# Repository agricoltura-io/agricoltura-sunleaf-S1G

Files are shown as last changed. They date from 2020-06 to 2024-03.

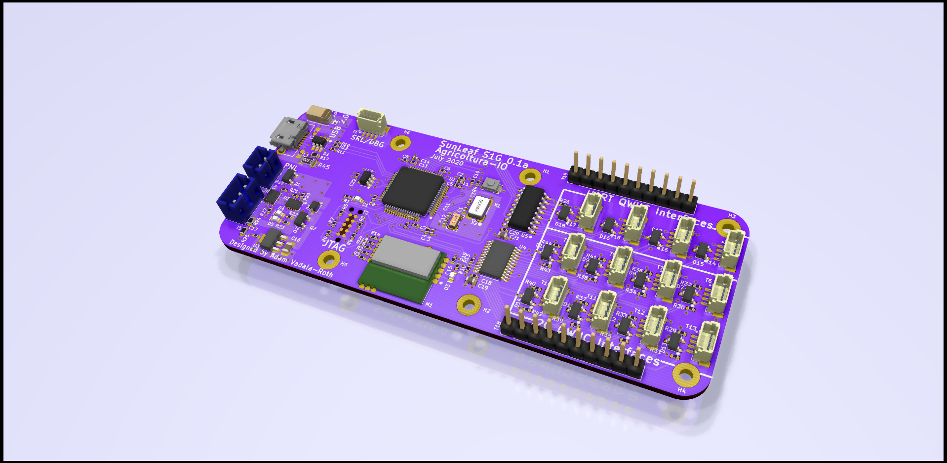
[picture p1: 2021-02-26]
PCB/agricoltura-SunLeaf-S1G/agricoltura-SunLeaf-S1G_angledRaytraced.png

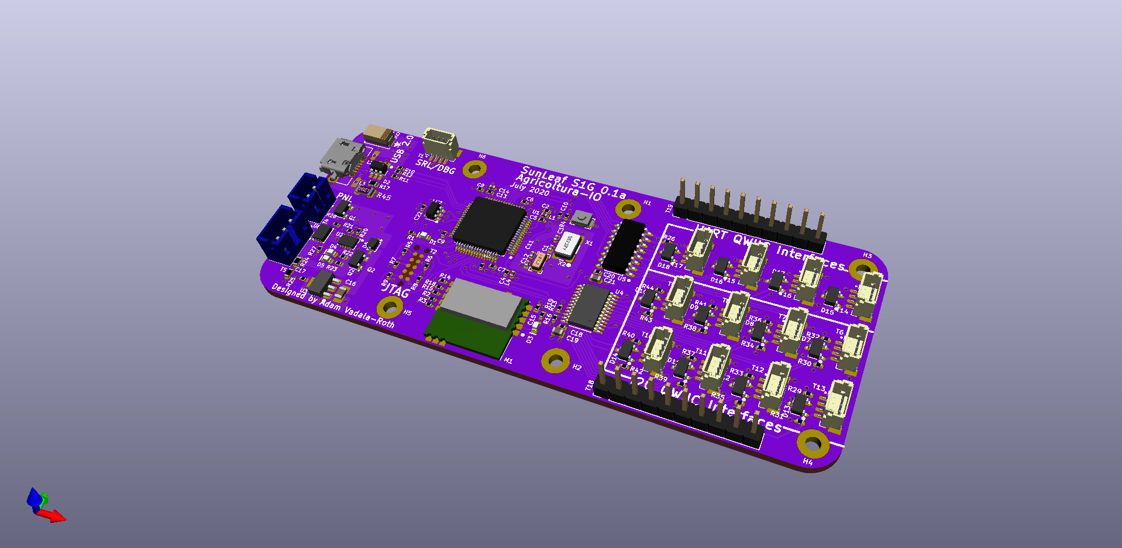
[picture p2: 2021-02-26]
PCB/agricoltura-SunLeaf-S1G/agricoltura-SunLeaf-S1G_angled.png

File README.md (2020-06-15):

# agricoltura-sunleaf-S1G
A new generation of the SunLeaf platform based on STM32 S1G radio module

Quick Specs:
- ST Microelectronics SPSGRF-915 STM32 ARM Cortex M0 915MHZ RF Module
- BQ240210 Lithium Ion Solar/USB charge controller and battery management 
- 500mA Lithium Polymer battery with thermistor 
- I2C ports
- UART ports
- Analog ports

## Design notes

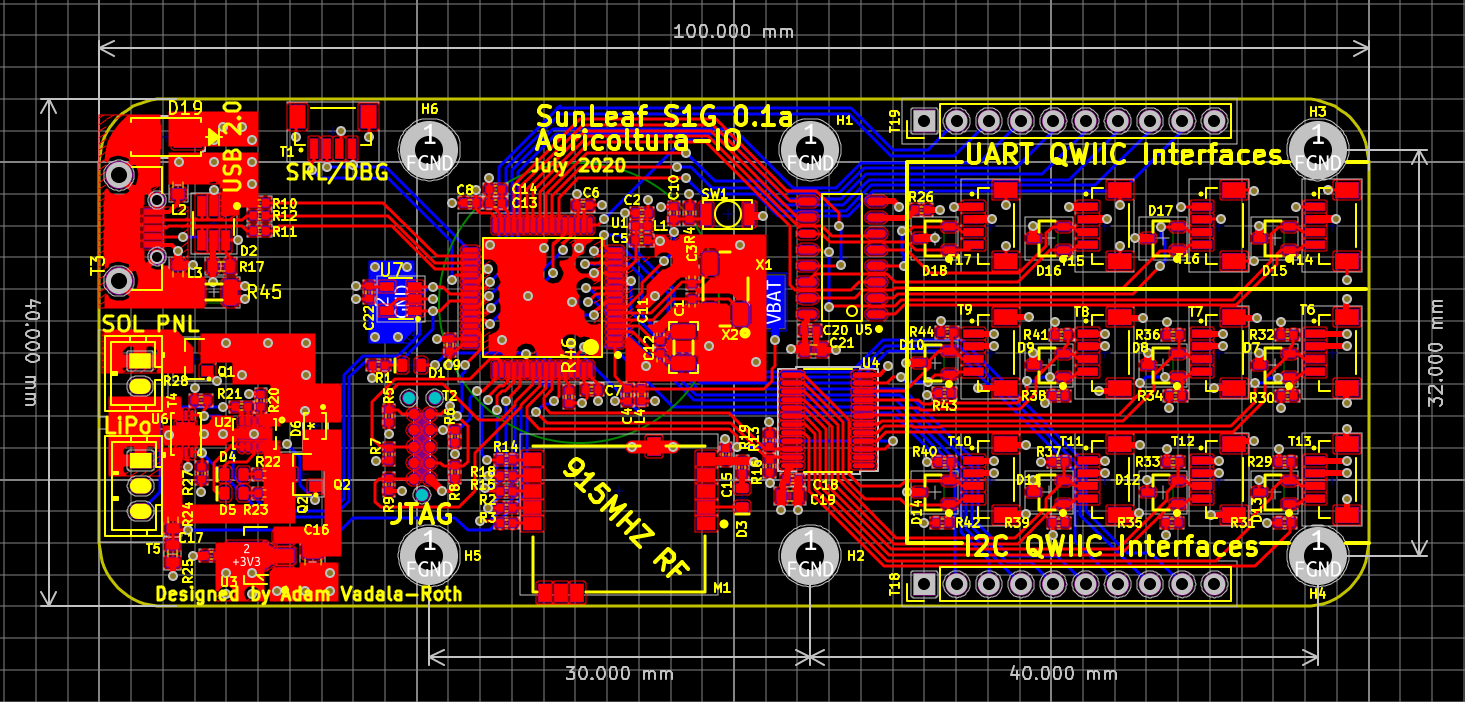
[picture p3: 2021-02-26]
PCB/agricoltura-SunLeaf-S1G/SunLeafS1G2D.png

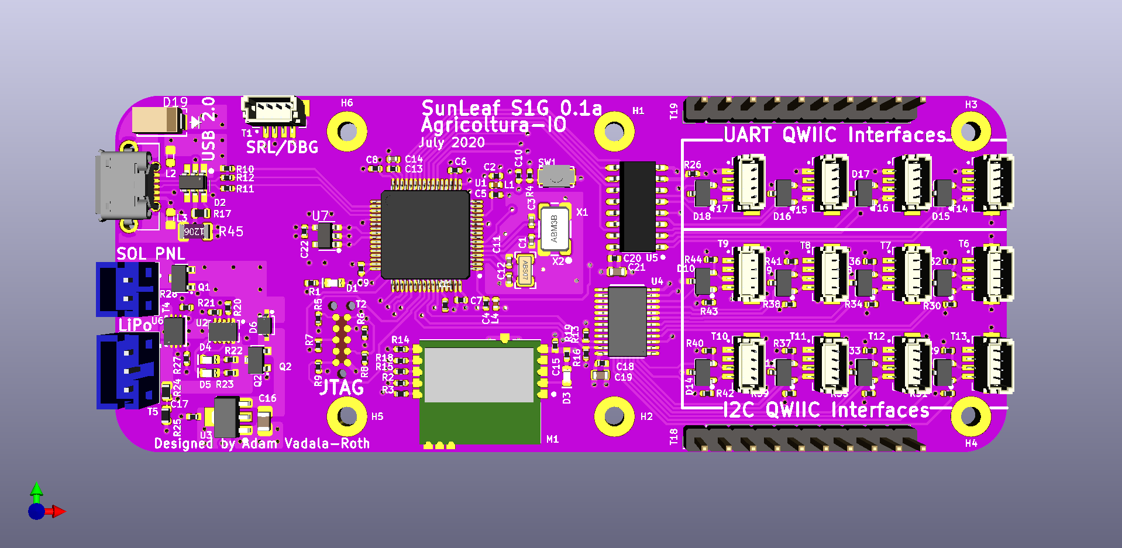
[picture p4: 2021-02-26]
PCB/agricoltura-SunLeaf-S1G/agricoltura-SunLeaf-S1G.png

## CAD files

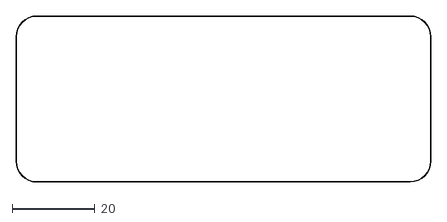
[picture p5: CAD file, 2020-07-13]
PCB/agricoltura-SunLeaf-S1G/SunLeaf_Board_Shape.dxf
100.0 x 40.0

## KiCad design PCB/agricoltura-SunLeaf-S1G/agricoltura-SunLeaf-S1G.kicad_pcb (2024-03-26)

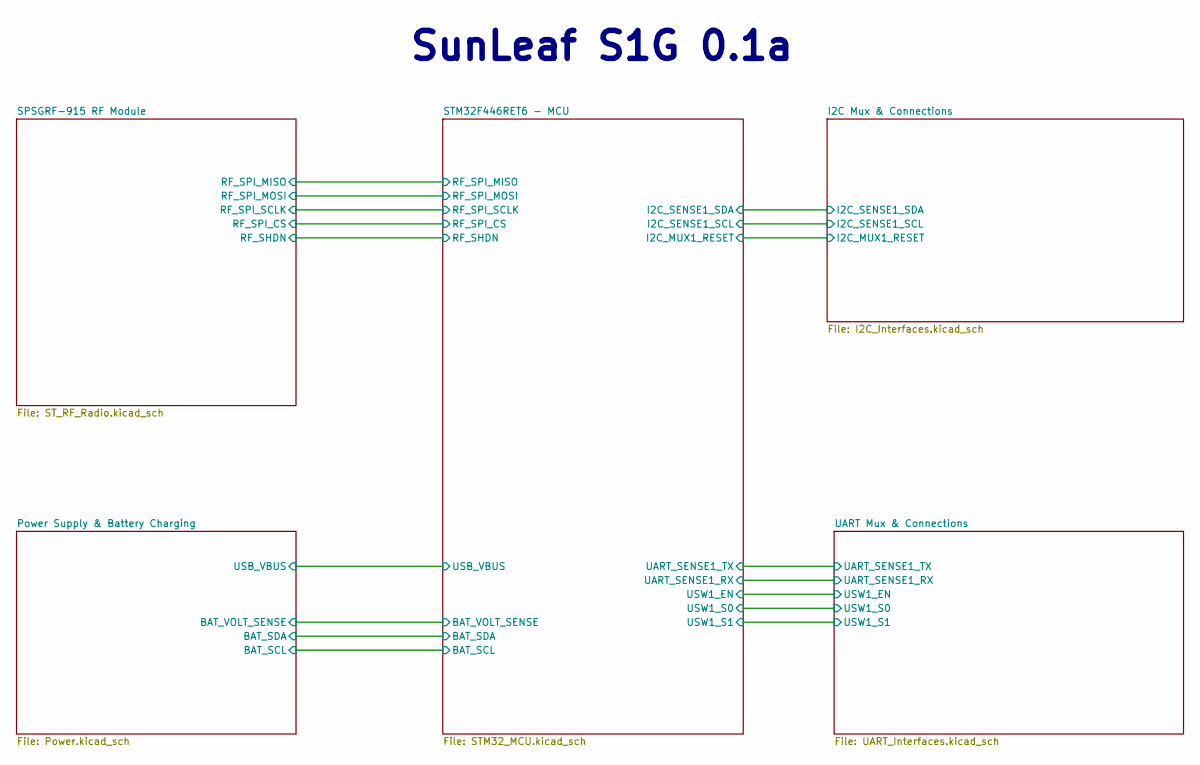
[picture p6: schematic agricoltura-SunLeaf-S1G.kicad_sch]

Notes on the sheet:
SunLeaf S1G 0.1a

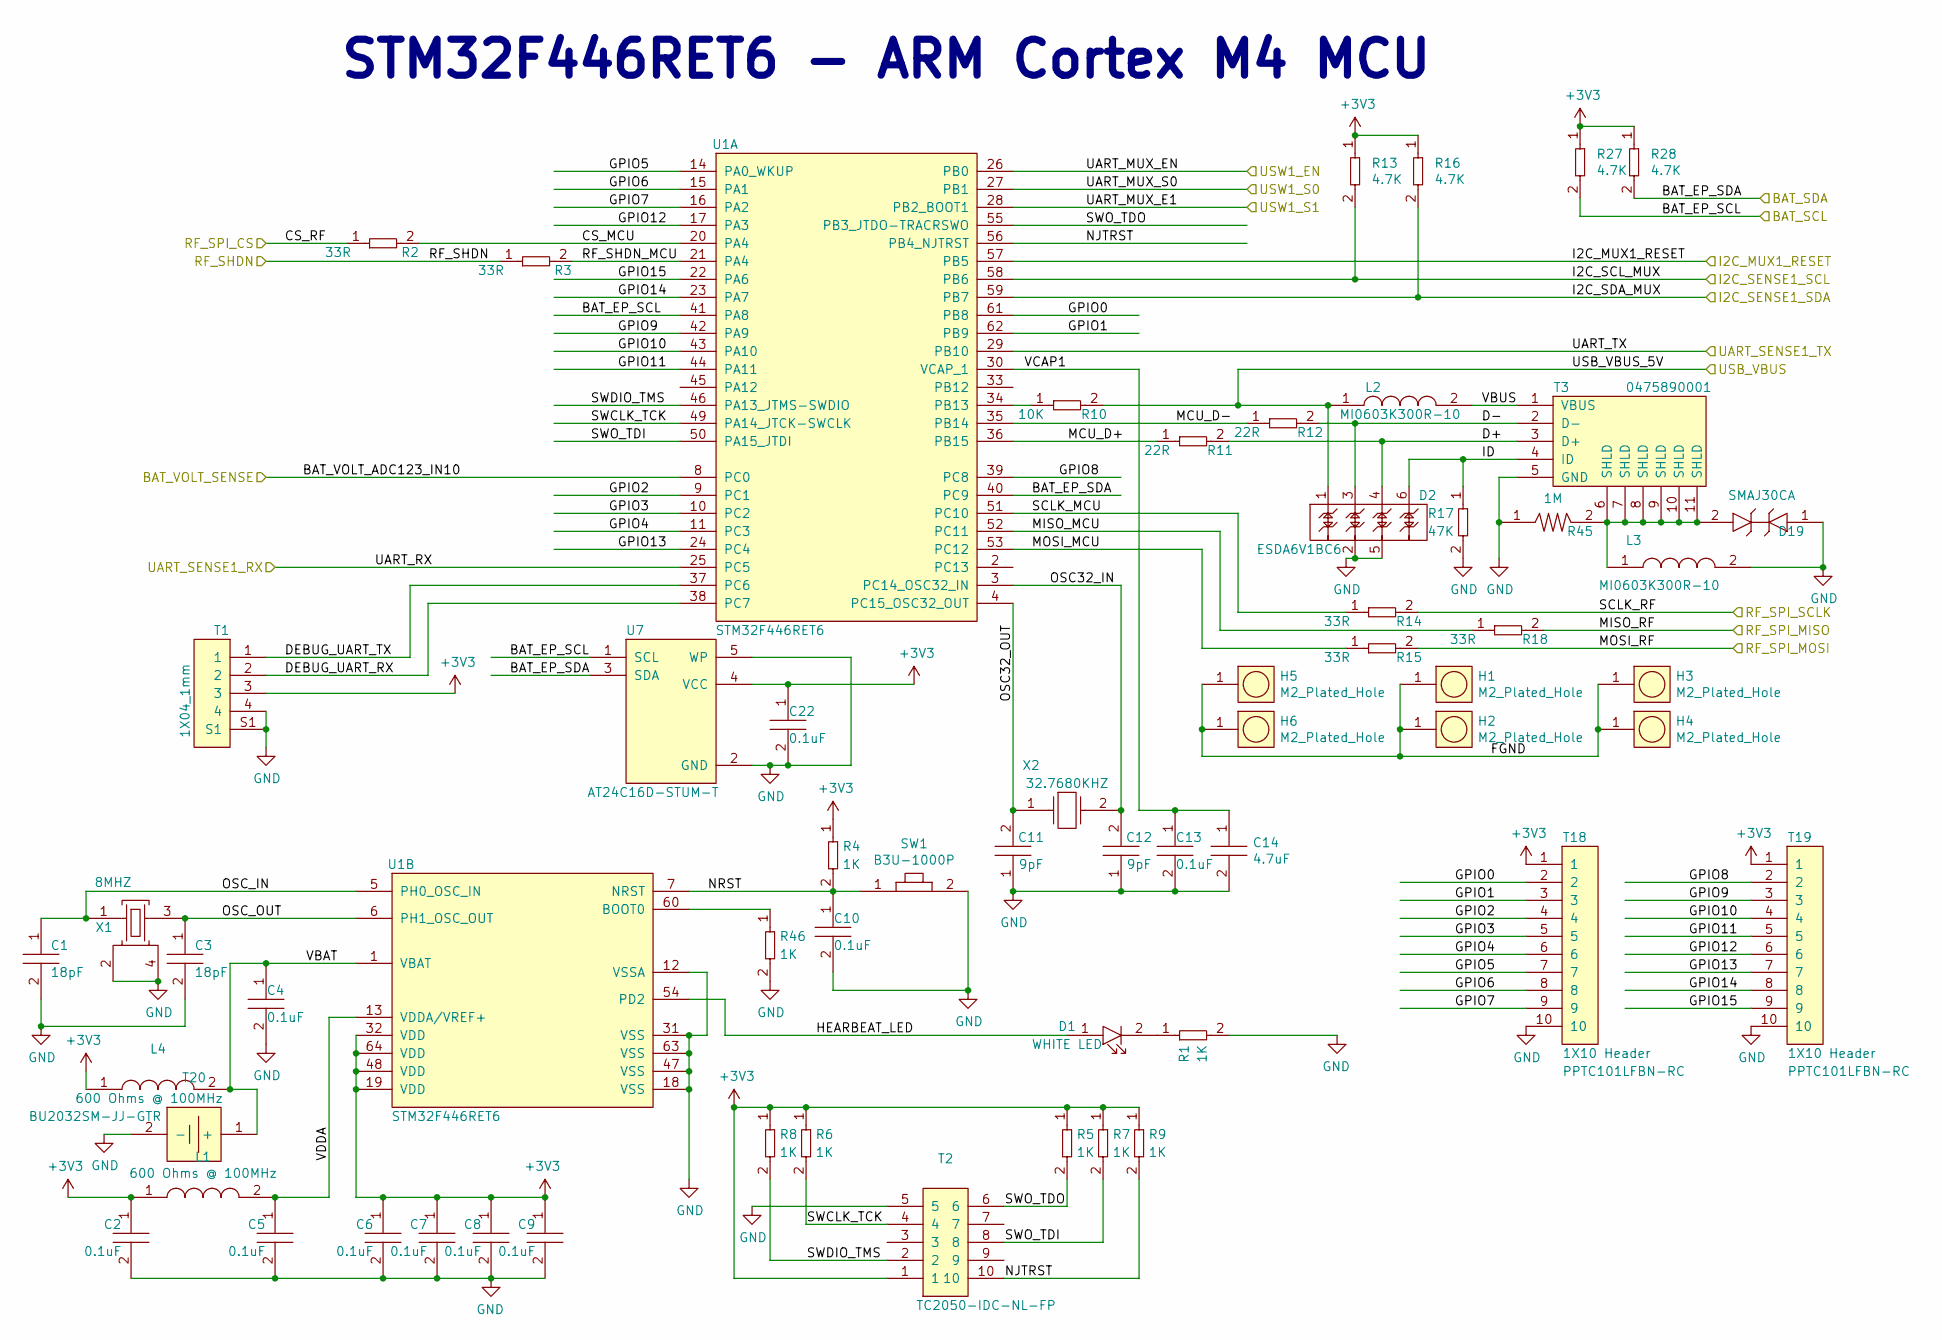
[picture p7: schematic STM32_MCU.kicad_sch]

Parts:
C1, C3: GCM1555C1H180GA16D; C0402; Tolerance 2%; Voltage 50V; MFR# GCM1555C1H180GA16D
C2, C4, C5, C6, C7, C8, C9, C10, C13, C22: C0402C104K9PACTU; R0402; Tolerance 10%; Voltage 6.3V; MFR# C0402C104K9PACTU
C11, C12: CL05C090CB5NNNC; C0402; Tolerance ±0.25pF; Voltage 50V; MFR# CL05C090CB5NNNC
C14: GRM155R60J475ME47D; C0402; Tolerance 20%; Voltage 6.3V; MFR# GRM155R60J475ME47D
D1: LW_Q38G_Q1OO_3K6L_1; LED0603; Tolerance *; Voltage 2.85V; MFR# LW Q38G-Q1OO-3K6L-1
D2: ESDA6V1BC6; SOT-23-6_Handsoldering; Tolerance *; Voltage 5V/6.1VBreakdown; MFR# ESDA6V1BC6
D19: SMAJ30CA; Tolerance *; Voltage 30V Clamp; MFR# SMAJ30CA
H1, H2, H3, H4, H5, H6: M2_Plated_Hole; M2_HOLE; Tolerance *; Voltage *; MFR# *
L1, L4: BLM15HG601SN1D; Tolerance *; Voltage *; MFR# BLM15HG601SN1D
L2, L3: MI0603K300R-10; Tolerance *; Voltage *; MFR# MI0603K300R-10
R1, R4, R5, R6, R7, R8, R9, R46: RC0402FR-071KL; R0402; Tolerance 1%; Voltage *; MFR# RC0402FR-071KL
R2, R3, R14, R15, R18: RC0402FR-0733RL; R0402; Tolerance 1%; Voltage *; MFR# RC0402FR-0733RL
R10: RC0402FR-0710KL; R0402; Tolerance 1%; Voltage *; MFR# RC0402FR-0710KL
R11, R12: RC0402FR-0722RL; R0402; Tolerance 1%; Voltage *; MFR# RC0402FR-0722RL
R13, R16, R27, R28: RC0402FR-074K7L; R0402; Tolerance 1%; Voltage *; MFR# RC0402FR-074K7L
R17: RC0603FR-0747KL; R0603; Tolerance 1%; Voltage *; MFR# RC0603FR-0747KL
R45: RC1206FR-071ML; R1206; Tolerance 1%; Voltage *; MFR# RC1206FR-071ML
SW1: B3U-1000P; Tolerance *; Voltage *; MFR# B3U-1000P
T1: BM04B-SRSS-TB(LF)(SN); CONN_BM04B-SRSS-TB(LF)(SN); Tolerance *; Voltage 50V; MFR# BM04B-SRSS-TB(LF)(SN)
T2: TC2050-IDC-NL-FP; TC2050-CLIP; Tolerance *; Voltage *; MFR# TC2050-IDC-NL-FP
T3: 0475890001; Tolerance *; Voltage 5V; MFR# 0475890001
T18, T19: PPTC101LFBN-RC; Female_Header_Straight_1x10_Pitch2.54mm; Tolerance *; Voltage 250V; MFR# PPTC101LFBN-RC
T20: BU2032SM-JJ-GTR; Tolerance *; Voltage 3.3V; MFR# BU2032SM-JJ-GTR
U1: STM32F446RET6; Tolerance *; Voltage 1.7V ~ 3.6V; MFR# STM32F446RET6
U7: AT24C16D-STUM-T; SOT-23-5; Tolerance *; Voltage 3.3V; MFR# AT24C16D-STUM-T
X1: ABM3B-8.000MHZ-B2-T; ABM3B8.000MHZB2T; Tolerance *; Voltage *; MFR# ABM3B-8.000MHZ-B2-T
X2: ABS07-32.768KHZ-9-T; Tolerance *; Voltage *; MFR# ABS07-32.768KHZ-9-T

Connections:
+3V3: C2.1, C6.1, C7.1, C8.1, C9.1, C22.1, L1.1, L4.1, R4.1, R5.1, R6.1, R7.1, R8.1, R9.1, R13.1, R16.1, R27.1, R28.1, T1.3, T2.1, T18.1, T19.1, U1.19 (VDD), U1.32 (VDD), U1.48 (VDD), U1.64 (VDD), U7.4 (VCC); also elsewhere on the board
/I2C Mux & Connections/I2C_MUX1_RESET: U1.57 (PB5); also elsewhere on the board
/I2C Mux & Connections/I2C_SENSE1_SCL: R13.2, U1.58 (PB6); also elsewhere on the board
/I2C Mux & Connections/I2C_SENSE1_SDA: R16.2, U1.59 (PB7); also elsewhere on the board
/Power Supply & Battery Charging/BAT_SCL: R27.2, U1.41 (PA8), U7.1 (SCL); also elsewhere on the board
/Power Supply & Battery Charging/BAT_SDA: R28.2, U1.40 (PC9), U7.3 (SDA); also elsewhere on the board
/Power Supply & Battery Charging/BAT_VOLT_SENSE: U1.8 (PC0); also elsewhere on the board
/Power Supply & Battery Charging/USB_VBUS: D2.1, L2.1, R10.2; also elsewhere on the board
/SPSGRF-915 RF Module /RF_SHDN: R3.1; also elsewhere on the board
/SPSGRF-915 RF Module /RF_SPI_CS: R2.1; also elsewhere on the board
/SPSGRF-915 RF Module /RF_SPI_MISO: R18.2; also elsewhere on the board
/SPSGRF-915 RF Module /RF_SPI_MOSI: R15.2; also elsewhere on the board
/SPSGRF-915 RF Module /RF_SPI_SCLK: R14.2; also elsewhere on the board
/STM32F446RET6 - MCU/CS_MCU: R2.2, U1.20 (PA4)
/STM32F446RET6 - MCU/D+: D2.4, R11.2, T3.3 (D+)
/STM32F446RET6 - MCU/D-: D2.3, R12.2, T3.2 (D-)
/STM32F446RET6 - MCU/DEBUG_UART_RX: T1.2, U1.38 (PC7)
/STM32F446RET6 - MCU/DEBUG_UART_TX: T1.1, U1.37 (PC6)
/STM32F446RET6 - MCU/FGND: H1.1, H2.1, H3.1, H4.1, H5.1, H6.1
/STM32F446RET6 - MCU/GPIO0: T18.2, U1.61 (PB8)
/STM32F446RET6 - MCU/GPIO1: T18.3, U1.62 (PB9)
/STM32F446RET6 - MCU/GPIO2: T18.4, U1.9 (PC1)
/STM32F446RET6 - MCU/GPIO3: T18.5, U1.10 (PC2)
/STM32F446RET6 - MCU/GPIO4: T18.6, U1.11 (PC3)
/STM32F446RET6 - MCU/GPIO5: T18.7, U1.14 (PA0_WKUP)
/STM32F446RET6 - MCU/GPIO6: T18.8, U1.15 (PA1)
/STM32F446RET6 - MCU/GPIO7: T18.9, U1.16 (PA2)
/STM32F446RET6 - MCU/GPIO8: T19.2, U1.39 (PC8)
/STM32F446RET6 - MCU/GPIO9: T19.3, U1.42 (PA9)
/STM32F446RET6 - MCU/GPIO10: T19.4, U1.43 (PA10)
/STM32F446RET6 - MCU/GPIO11: T19.5, U1.44 (PA11)
/STM32F446RET6 - MCU/GPIO12: T19.6, U1.17 (PA3)
/STM32F446RET6 - MCU/GPIO13: T19.7, U1.24 (PC4)
/STM32F446RET6 - MCU/GPIO14: T19.8, U1.23 (PA7)
/STM32F446RET6 - MCU/GPIO15: T19.9, U1.22 (PA6)
/STM32F446RET6 - MCU/HEARBEAT_LED: D1.1, U1.54 (PD2)
/STM32F446RET6 - MCU/ID: D2.6, R17.1, T3.4 (ID)
/STM32F446RET6 - MCU/MCU_D+: R11.1, U1.36 (PB15)
/STM32F446RET6 - MCU/MCU_D-: R12.1, U1.35 (PB14)
/STM32F446RET6 - MCU/MISO_MCU: R18.1, U1.52 (PC11)
/STM32F446RET6 - MCU/MOSI_MCU: R15.1, U1.53 (PC12)
/STM32F446RET6 - MCU/NJTRST: R9.2, T2.10, U1.56 (PB4_NJTRST)
/STM32F446RET6 - MCU/NRST: C10.1, R4.2, SW1.1, U1.7 (NRST)
/STM32F446RET6 - MCU/OSC32_IN: C12.2, U1.3 (PC14_OSC32_IN), X2.2
/STM32F446RET6 - MCU/OSC32_OUT: C11.2, U1.4 (PC15_OSC32_OUT), X2.1
/STM32F446RET6 - MCU/OSC_IN: C1.1, U1.5 (PH0_OSC_IN), X1.1
/STM32F446RET6 - MCU/OSC_OUT: C3.1, U1.6 (PH1_OSC_OUT), X1.3
/STM32F446RET6 - MCU/RF_SHDN_MCU: R3.2, U1.21 (PA4)
/STM32F446RET6 - MCU/SCLK_MCU: R14.1, U1.51 (PC10)
/STM32F446RET6 - MCU/SWCLK_TCK: R6.2, T2.4, U1.49 (PA14_JTCK-SWCLK)
/STM32F446RET6 - MCU/SWDIO_TMS: R8.2, T2.2, U1.46 (PA13_JTMS-SWDIO)
/STM32F446RET6 - MCU/SWO_TDI: R7.2, T2.8, U1.50 (PA15_JTDI)
/STM32F446RET6 - MCU/SWO_TDO: R5.2, T2.6, U1.55 (PB3_JTDO-TRACRSWO)
/STM32F446RET6 - MCU/UART_SENSE1_RX: U1.25 (PC5); also elsewhere on the board
/STM32F446RET6 - MCU/UART_SENSE1_TX: U1.29 (PB10); also elsewhere on the board
/STM32F446RET6 - MCU/USW1_EN: U1.26 (PB0); also elsewhere on the board
/STM32F446RET6 - MCU/USW1_S0: U1.27 (PB1); also elsewhere on the board
/STM32F446RET6 - MCU/USW1_S1: U1.28 (PB2_BOOT1); also elsewhere on the board
/STM32F446RET6 - MCU/VBAT: C4.1, L4.2, T20.1 (+), U1.1 (VBAT)
/STM32F446RET6 - MCU/VBUS: L2.2, T3.1 (VBUS)
/STM32F446RET6 - MCU/VCAP1: C13.1, C14.1, U1.30 (VCAP_1)
/STM32F446RET6 - MCU/VDDA: C5.1, L1.2, U1.13 (VDDA/VREF+)
GND: C1.2, C2.2, C3.2, C4.2, C5.2, C6.2, C7.2, C8.2, C9.2, C10.2, C11.1, C12.1, C13.2, C14.2, C22.2, D2.2, D2.5, D19.1, L3.2, R1.2, R17.2, R45.1, R46.2, SW1.2, T1.4, T1.S1, T2.5, T3.5 (GND), T18.10, T19.10, T20.2 (-), U1.12 (VSSA), U1.18 (VSS), U1.31 (VSS), U1.47 (VSS), U1.63 (VSS), U7.2 (GND), U7.5 (WP), X1.2, X1.4; also elsewhere on the board
unnamed: D1.2, R1.1
unnamed: D19.2, L3.1, R45.2, T3.6 (SHLD), T3.7 (SHLD), T3.8 (SHLD), T3.9 (SHLD), T3.10 (SHLD), T3.11 (SHLD)
unnamed: R10.1, U1.34 (PB13)
unnamed: R46.1, U1.60 (BOOT0)

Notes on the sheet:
STM32F446RET6 - ARM Cortex M4 MCU

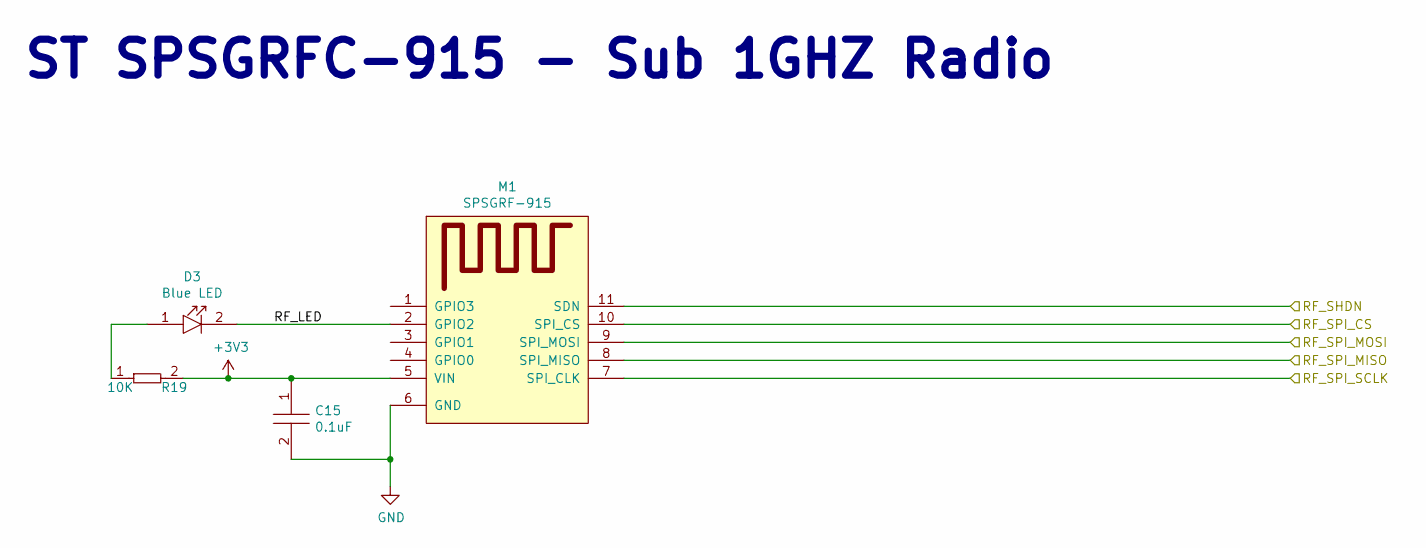
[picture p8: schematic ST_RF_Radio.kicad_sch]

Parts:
C15: C0402C104K9PACTU; R0402; Tolerance 10%; Voltage 6.3V; MFR# C0402C104K9PACTU
D3: LTST-C194TBKT; LED0603; Tolerance *; Voltage 3.3V; MFR# LTST-C194TBKT
M1: SPSGRF-915; XCVR_SPSGRF-915; Tolerance *; Voltage 1.8V ~ 3.6V; MFR# SPSGRF-915
R19: RC0402FR-0710KL; R0402; Tolerance 1%; Voltage *; MFR# RC0402FR-0710KL

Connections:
+3V3: C15.1, M1.5 (VIN), R19.2; also elsewhere on the board
/SPSGRF-915 RF Module /RF_LED: D3.2, M1.2 (GPIO2)
/SPSGRF-915 RF Module /RF_SHDN: M1.11 (SDN); also elsewhere on the board
/SPSGRF-915 RF Module /RF_SPI_CS: M1.10 (SPI_CS); also elsewhere on the board
/SPSGRF-915 RF Module /RF_SPI_MISO: M1.8 (SPI_MISO); also elsewhere on the board
/SPSGRF-915 RF Module /RF_SPI_MOSI: M1.9 (SPI_MOSI); also elsewhere on the board
/SPSGRF-915 RF Module /RF_SPI_SCLK: M1.7 (SPI_CLK); also elsewhere on the board
GND: C15.2, M1.6 (GND); also elsewhere on the board
unnamed: D3.1, R19.1

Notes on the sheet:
ST SPSGRFC-915 - Sub 1GHZ Radio

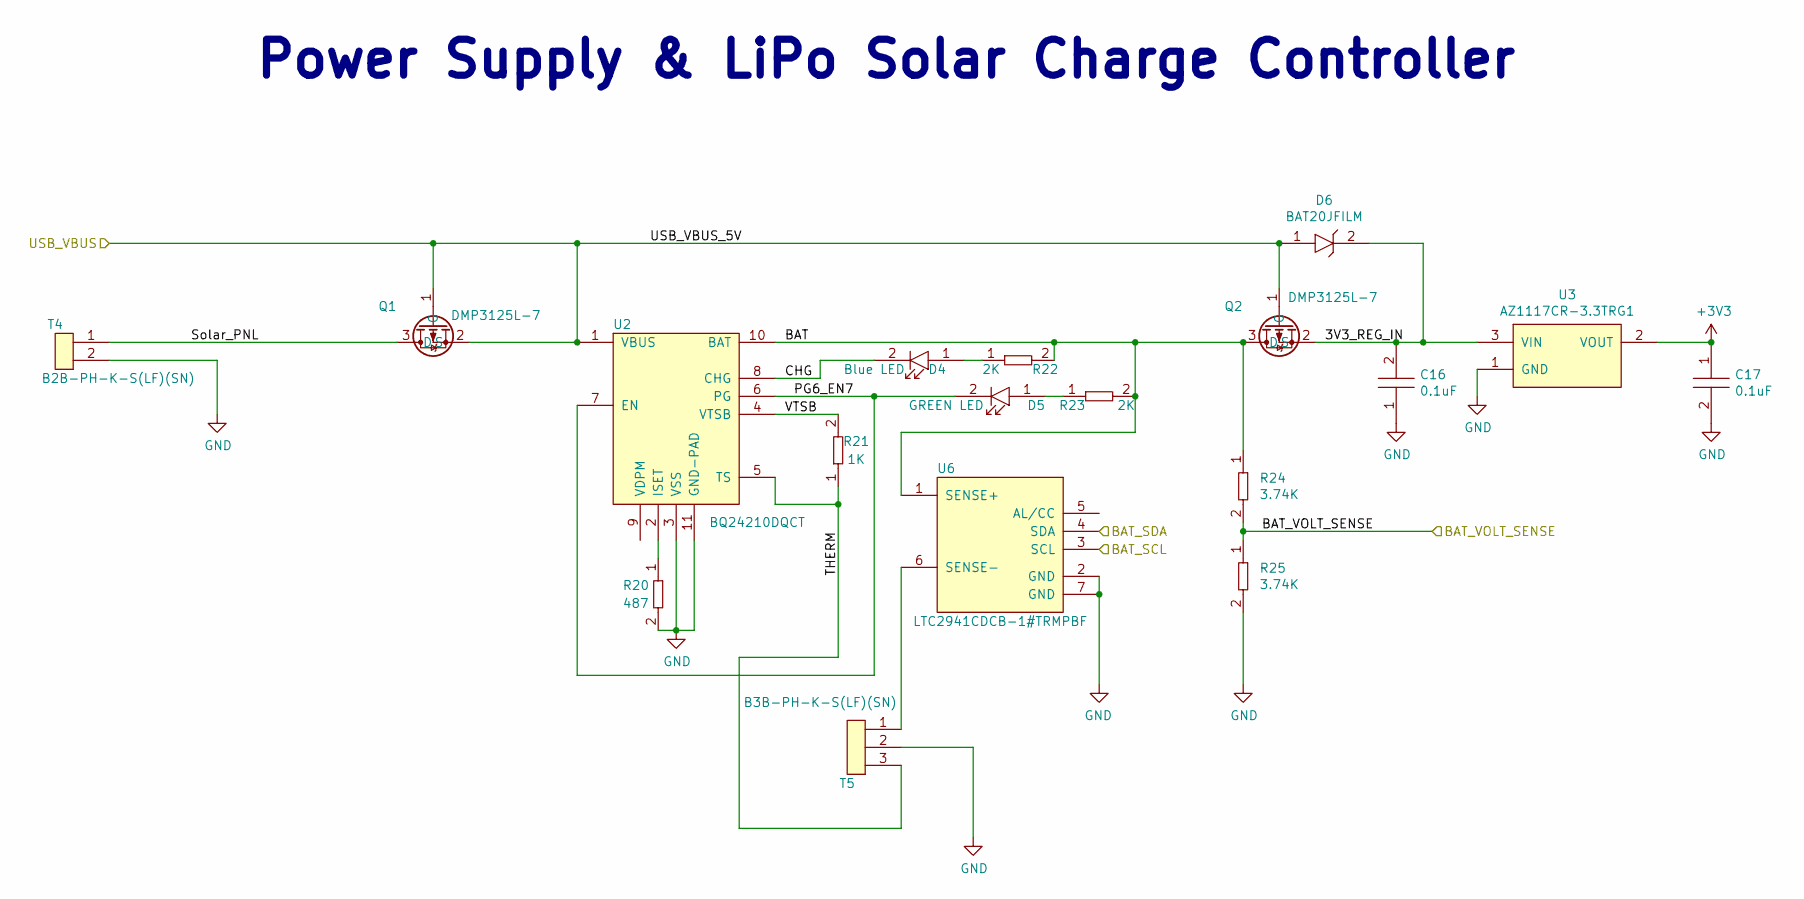
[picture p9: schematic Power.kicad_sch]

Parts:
C16: C0805C104M5RACTU; C0805; Tolerance 20%; Voltage 50V; MFR# C0805C104M5RACTU
C17: C0402C104K9PACTU; R0402; Tolerance 10%; Voltage 6.3V; MFR# C0402C104K9PACTU
D4: LTST-C194TBKT; LED0603; Tolerance *; Voltage 3.3V; MFR# LTST-C194TBKT
D5: LTST-C194KGKT; LED0603; Tolerance *; Voltage 2.1V; MFR# LTST-C194KGKT
D6: BAT20JFILM; Tolerance *; Voltage 23V; MFR# BAT20JFILM
Q1, Q2: DMP3125L-7; SOT-23; Tolerance *; Voltage 20V; MFR# DMP3125L-7
R20: RC0402FR-07487RL; R0402; Tolerance 1%; Voltage *; MFR# RC0402FR-07487RL
R21: RC0402FR-071KL; R0402; Tolerance 1%; Voltage *; MFR# RC0402FR-071KL
R22, R23: RC0402FR-072KL; R0402; Tolerance 1%; Voltage *; MFR# RC0402FR-072KL
R24, R25: ERA-3AEB3741V; R0603; Tolerance 1%; Voltage *; MFR# ERA-3AEB3741V
T4: B2B-PH-K-S(LF)(SN); Tolerance *; Voltage 100V; MFR# B2B-PH-K-S(LF)(SN)
T5: B3B-PH-K-S(LF)(SN); Tolerance *; Voltage 100V; MFR# B3B-PH-K-S(LF)(SN)
U2: BQ24210DQCT; BQ24210; Tolerance *; Voltage 18V MAX IN, 4.2V BATT MAX; MFR# BQ24210DQCT
U3: AZ1117CR-3.3TRG1; SOT_89; Tolerance *; Voltage 15IN, 3V3 OUT; MFR# AZ1117CR-3.3TRG1
U6: LTC2941CDCB-1#TRMPBF; LTC2941CDCB-1-TRMPBF; Tolerance *; Voltage *; MFR# LTC2941CDCB-1#TRMPBF

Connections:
+3V3: C17.1, U3.2 (VOUT); also elsewhere on the board
/Power Supply & Battery Charging/3V3_REG_IN: C16.2, D6.2, Q2.2 (S), U3.3 (VIN)
/Power Supply & Battery Charging/BAT: Q2.3 (D), R22.2, R23.2, R24.1, U2.10 (BAT), U6.1 (SENSE+)
/Power Supply & Battery Charging/BAT_SCL: U6.3 (SCL); also elsewhere on the board
/Power Supply & Battery Charging/BAT_SDA: U6.4 (SDA); also elsewhere on the board
/Power Supply & Battery Charging/BAT_VOLT_SENSE: R24.2, R25.1; also elsewhere on the board
/Power Supply & Battery Charging/CHG: D4.2, U2.8 (CHG)
/Power Supply & Battery Charging/PG6_EN7: D5.2, U2.6 (PG), U2.7 (EN)
/Power Supply & Battery Charging/Solar_PNL: Q1.3 (D), T4.1
/Power Supply & Battery Charging/THERM: R21.1, T5.3, U2.5 (TS)
/Power Supply & Battery Charging/USB_VBUS: D6.1, Q1.1 (G), Q1.2 (S), Q2.1 (G), U2.1 (VBUS); also elsewhere on the board
/Power Supply & Battery Charging/VTSB: R21.2, U2.4 (VTSB)
GND: C16.1, C17.2, R20.2, R25.2, T4.2, T5.2, U2.3 (VSS), U2.11 (GND-PAD), U3.1 (GND), U6.2 (GND), U6.7 (GND); also elsewhere on the board
unnamed: D4.1, R22.1
unnamed: D5.1, R23.1
unnamed: R20.1, U2.2 (ISET)
unnamed: T5.1, U6.6 (SENSE-)

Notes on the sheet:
Power Supply & LiPo Solar Charge Controller

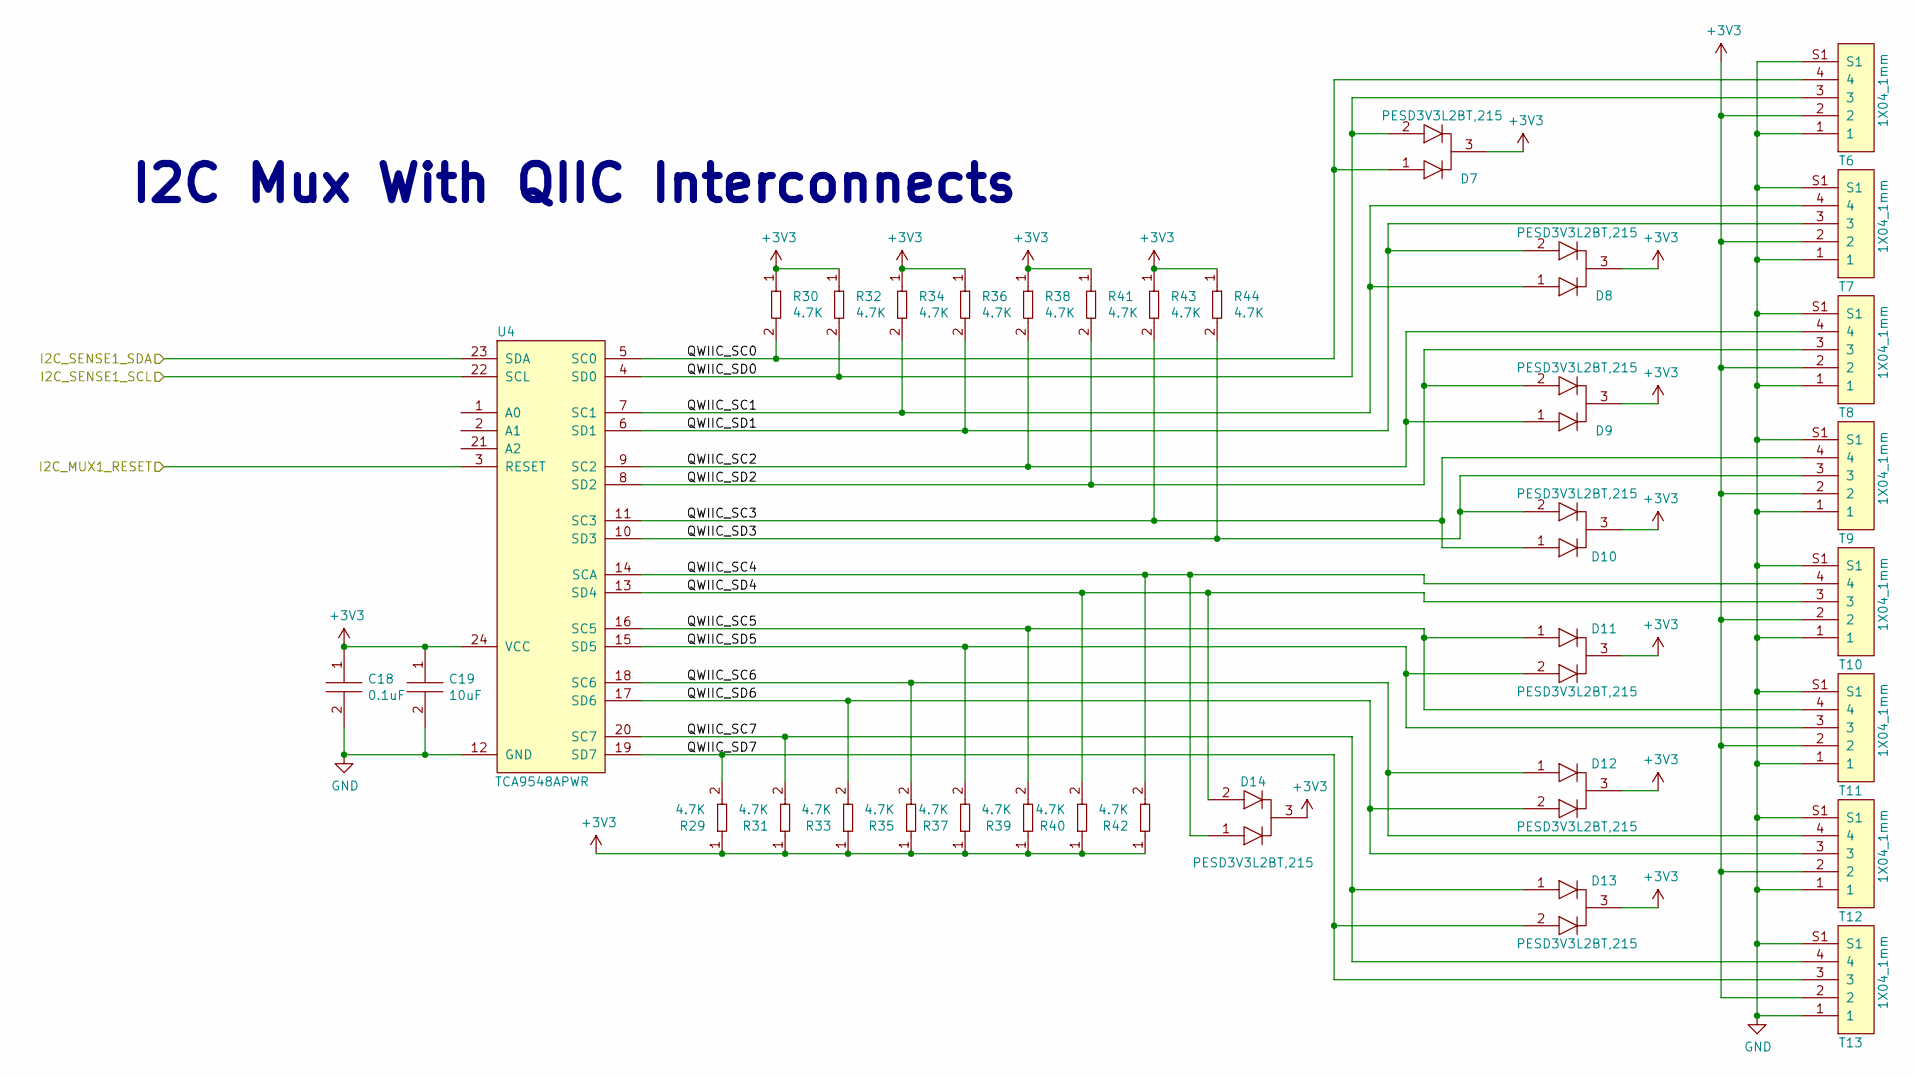
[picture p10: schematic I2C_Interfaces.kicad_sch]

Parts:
C18: C0402C104K9PACTU; R0402; Tolerance 10%; Voltage 6.3V; MFR# C0402C104K9PACTU
C19: GRM188R61A106KE69J; C0603; Tolerance 10%; Voltage 10V; MFR# GRM188R61A106KE69J
D7, D8, D9, D10, D11, D12, D13, D14: PESD3V3L2BT,215; SOT-23; Tolerance *; Voltage *; MFR# PESD3V3L2BT,215
R29, R30, R31, R32, R33, R34, R35, R36, R37, R38, R39, R40, R41, R42, R43, R44: RC0402FR-074K7L; R0402; Tolerance 1%; Voltage *; MFR# RC0402FR-074K7L
T6, T7, T8, T9, T10, T11, T12, T13: BM04B-SRSS-TB(LF)(SN); CONN_BM04B-SRSS-TB(LF)(SN); Tolerance *; Voltage 50V; MFR# BM04B-SRSS-TB(LF)(SN)
U4: TCA9548APWR; Tolerance *; Voltage 1.65V ~ 5.5V; MFR# TCA9548APWR

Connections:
+3V3: C18.1, C19.1, D7.3, D8.3, D9.3, D10.3, D11.3, D12.3, D13.3, D14.3, R29.1, R30.1, R31.1, R32.1, R33.1, R34.1, R35.1, R36.1, R37.1, R38.1, R39.1, R40.1, R41.1, R42.1, R43.1, R44.1, T6.2, T7.2, T8.2, T9.2, T10.2, T11.2, T12.2, T13.2, U4.24 (VCC); also elsewhere on the board
/I2C Mux & Connections/I2C_MUX1_RESET: U4.3 (RESET); also elsewhere on the board
/I2C Mux & Connections/I2C_SENSE1_SCL: U4.22 (SCL); also elsewhere on the board
/I2C Mux & Connections/I2C_SENSE1_SDA: U4.23 (SDA); also elsewhere on the board
/I2C Mux & Connections/QWIIC_SC0: D7.1, R30.2, T6.4, U4.5 (SC0)
/I2C Mux & Connections/QWIIC_SC1: D8.1, R34.2, T7.4, U4.7 (SC1)
/I2C Mux & Connections/QWIIC_SC2: D9.1, R38.2, T8.4, U4.9 (SC2)
/I2C Mux & Connections/QWIIC_SC3: D10.1, R43.2, T9.4, U4.11 (SC3)
/I2C Mux & Connections/QWIIC_SC4: D14.1, R42.2, T10.4, U4.14 (SCA)
/I2C Mux & Connections/QWIIC_SC5: D11.1, R39.2, T11.4, U4.16 (SC5)
/I2C Mux & Connections/QWIIC_SC6: D12.1, R35.2, T12.4, U4.18 (SC6)
/I2C Mux & Connections/QWIIC_SC7: D13.1, R31.2, T13.4, U4.20 (SC7)
/I2C Mux & Connections/QWIIC_SD0: D7.2, R32.2, T6.3, U4.4 (SD0)
/I2C Mux & Connections/QWIIC_SD1: D8.2, R36.2, T7.3, U4.6 (SD1)
/I2C Mux & Connections/QWIIC_SD2: D9.2, R41.2, T8.3, U4.8 (SD2)
/I2C Mux & Connections/QWIIC_SD3: D10.2, R44.2, T9.3, U4.10 (SD3)
/I2C Mux & Connections/QWIIC_SD4: D14.2, R40.2, T10.3, U4.13 (SD4)
/I2C Mux & Connections/QWIIC_SD5: D11.2, R37.2, T11.3, U4.15 (SD5)
/I2C Mux & Connections/QWIIC_SD6: D12.2, R33.2, T12.3, U4.17 (SD6)
/I2C Mux & Connections/QWIIC_SD7: D13.2, R29.2, T13.3, U4.19 (SD7)
GND: C18.2, C19.2, T6.1, T6.S1, T7.1, T7.S1, T8.1, T8.S1, T9.1, T9.S1, T10.1, T10.S1, T11.1, T11.S1, T12.1, T12.S1, T13.1, T13.S1, U4.12 (GND); also elsewhere on the board

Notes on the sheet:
I2C Mux With QIIC Interconnects

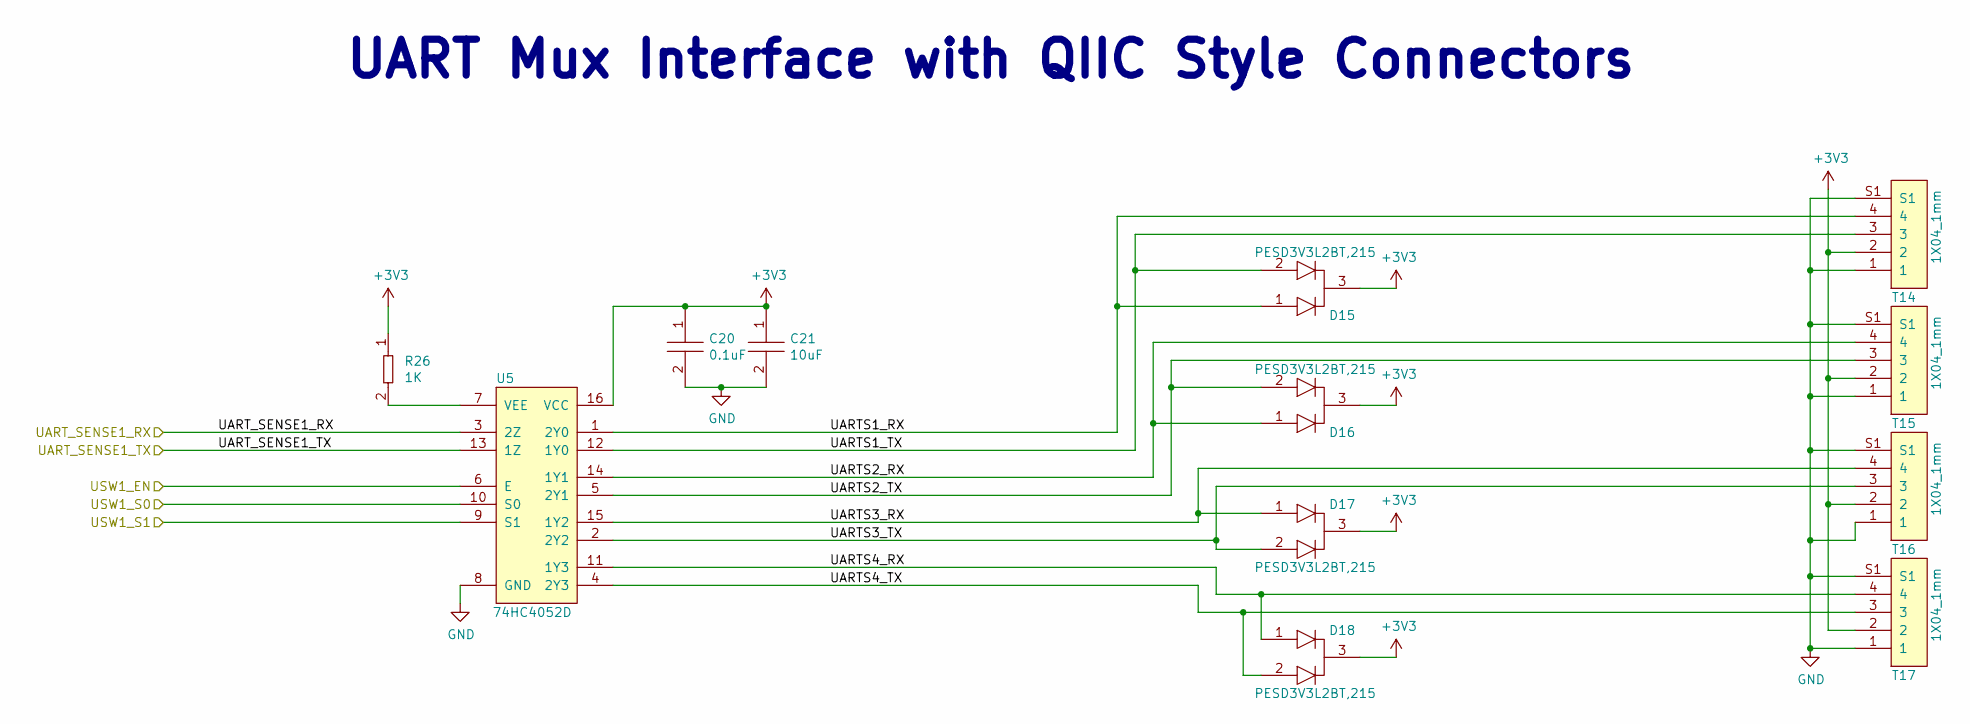
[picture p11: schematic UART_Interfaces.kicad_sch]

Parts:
C20: C0402C104K9PACTU; R0402; Tolerance 10%; Voltage 6.3V; MFR# C0402C104K9PACTU
C21: GRM188R61A106KE69J; C0603; Tolerance 10%; Voltage 10V; MFR# GRM188R61A106KE69J
D15, D16, D17, D18: PESD3V3L2BT,215; SOT-23; Tolerance *; Voltage *; MFR# PESD3V3L2BT,215
R26: RC0402FR-071KL; R0402; Tolerance 1%; Voltage *; MFR# RC0402FR-071KL
T14, T15, T16, T17: BM04B-SRSS-TB(LF)(SN); CONN_BM04B-SRSS-TB(LF)(SN); Tolerance *; Voltage 50V; MFR# BM04B-SRSS-TB(LF)(SN)
U5: 74HC4052D; Tolerance *; Voltage 2V ~ 6V; MFR# 74HC4052D

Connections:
+3V3: C20.1, C21.1, D15.3, D16.3, D17.3, D18.3, R26.1, T14.2, T15.2, T16.2, T17.2, U5.16 (VCC); also elsewhere on the board
/STM32F446RET6 - MCU/UART_SENSE1_RX: U5.3 (2Z); also elsewhere on the board
/STM32F446RET6 - MCU/UART_SENSE1_TX: U5.13 (1Z); also elsewhere on the board
/STM32F446RET6 - MCU/USW1_EN: U5.6 (E); also elsewhere on the board
/STM32F446RET6 - MCU/USW1_S0: U5.10 (S0); also elsewhere on the board
/STM32F446RET6 - MCU/USW1_S1: U5.9 (S1); also elsewhere on the board
/UART Mux & Connections/UARTS1_RX: D15.1, T14.4, U5.1 (2Y0)
/UART Mux & Connections/UARTS1_TX: D15.2, T14.3, U5.12 (1Y0)
/UART Mux & Connections/UARTS2_RX: D16.1, T15.4, U5.14 (1Y1)
/UART Mux & Connections/UARTS2_TX: D16.2, T15.3, U5.5 (2Y1)
/UART Mux & Connections/UARTS3_RX: D17.1, T16.4, U5.15 (1Y2)
/UART Mux & Connections/UARTS3_TX: D17.2, T16.3, U5.2 (2Y2)
/UART Mux & Connections/UARTS4_RX: D18.1, T17.4, U5.11 (1Y3)
/UART Mux & Connections/UARTS4_TX: D18.2, T17.3, U5.4 (2Y3)
GND: C20.2, C21.2, T14.1, T14.S1, T15.1, T15.S1, T16.1, T16.S1, T17.1, T17.S1, U5.8 (GND); also elsewhere on the board
unnamed: R26.2, U5.7 (VEE)

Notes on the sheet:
UART Mux Interface with QIIC Style Connectors

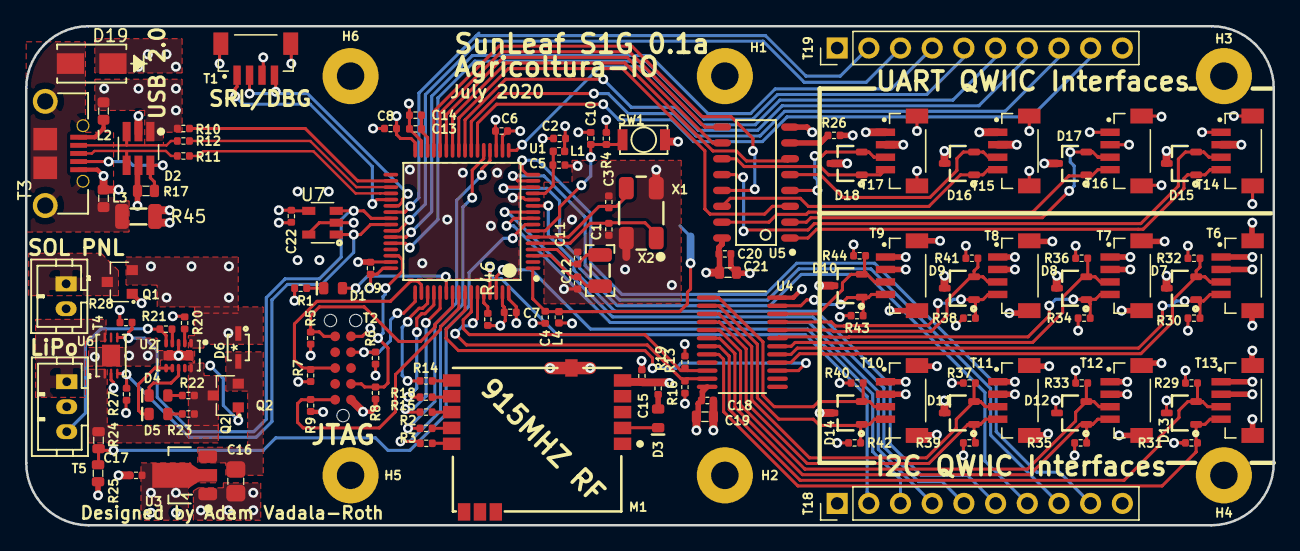
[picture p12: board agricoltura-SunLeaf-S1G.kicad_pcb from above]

Board: 4 copper layers, 100.0 x 40.0 mm, 130 parts (1 on the bottom side), 105 nets.

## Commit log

2020-07-08 Schematic Progress
    Schematic struture created, copied over circuits from Vine that are identical.
    [I2C_Interfaces.sch, Power.sch, STM32_MCU.sch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]
2020-07-10 Power Supply and Datasheets
    Added datasheets for parts in use, designed power supply circuit
    [Power.sch, STM32_MCU.sch, ST_RF_Radio.sch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]
2020-07-12 Schematic Complete
    Schematic completed and PCB started
    [I2C_Interfaces.sch, Power.sch, STM32_MCU.sch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]
2020-07-13 PCB Progress
    added TVS diodes fo QWIIC connector serial signals. Did more routing overall.
    [I2C_Interfaces.sch, Power.sch, STM32_MCU.sch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]
2020-07-18 Pullups
    Added pullup reistors to I2C ports, changed JTAG connector over to Tag connect.
    [I2C_Interfaces.sch, Power.sch, STM32_MCU.sch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]
2020-07-19 PCB Progress
    PCB routing progress made, USB port replaced with micro b like older sunleaf designs.
    [STM32_MCU.sch, agricoltura-SunLeaf-S1G.sch]
2020-07-20 Routing Complete
    Board routing completed, also added EEPROM for storing configuration settings.
    [Power.sch, STM32_MCU.sch, agricoltura-SunLeaf-S1G.kicad_pcb]
2020-07-22 Adjusted Copper
    Adjusted copper pours and via placement underneath MCU
    [agricoltura-SunLeaf-S1G.kicad_pcb]
2021-02-26 Pix
    Pictures added
    [agricoltura-SunLeaf-S1G.kicad_pcb]
2024-03-26 KiCAD 8
    Projected updated to KiCAD 8
    [I2C_Interfaces.kicad_sch, Power.kicad_sch, STM32_MCU.kicad_sch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]

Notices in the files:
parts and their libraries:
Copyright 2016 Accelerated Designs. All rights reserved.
